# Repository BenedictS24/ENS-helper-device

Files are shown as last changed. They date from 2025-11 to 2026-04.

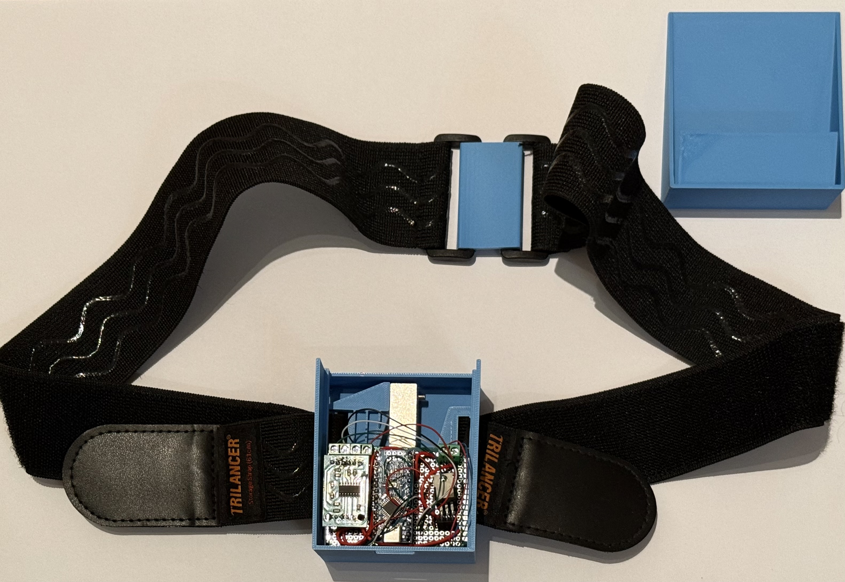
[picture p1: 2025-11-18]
images/device_open.jpeg

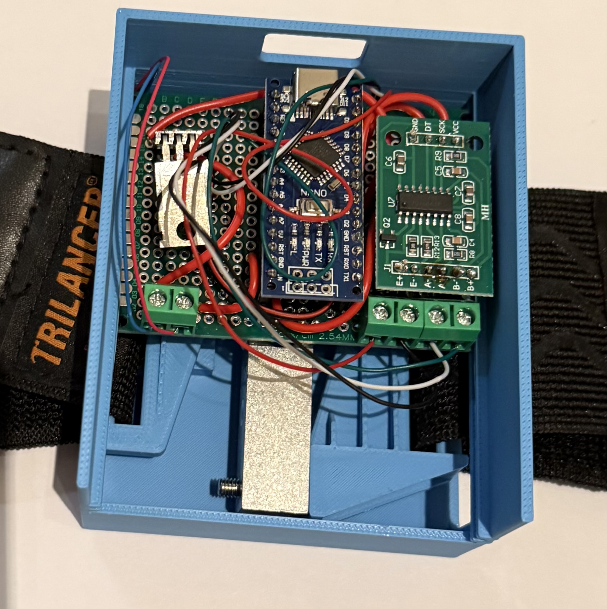
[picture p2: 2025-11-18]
images/protoboard_in_case.jpeg

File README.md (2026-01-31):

# ENS Helper Device

A chest-mounted haptic feedback belt that helps people with Empty Nose Syndrome (ENS) perceive their breathing again.
The device measures chest expansion using a load cell connected to a strap and translates this signal into vibrations via a small vibration motor embedded in the device.

---
## Repository Structure

```
ENS-helper-device/
├── .gitignore
├── KiCad/
│   ├── sensory_support_device.kicad_pcb
│   └── sensory_support_device.kicad_sch
├── README.md
├── force_vibration_controller/
│   └── force_vibration_controller.ino
├── images/
│   ├── PCB-3d.png
│   ├── PCB.png
│   ├── breadboard_circuit.jpeg
│   ├── circuit.png
│   ├── device_closed.jpeg
│   ├── device_open.jpeg
│   ├── device_worn.JPG
│   └── protoboard_in_case.jpeg
└── models/
    ├── back_plate.stl
    ├── load_cell_attachment.stl
    ├── main_plate.stl
    └── main_plate_cover.stl
```

---
## Overview

People with Empty Nose Syndrome often struggle to feel the airflow in their nose, which can make it harder to sense their own breathing and can greatly impact everyday life and well-being.  
This device offers an alternative channel: **haptic feedback on the chest**.

1. A chest strap attached to a **bar-type load cell** is placed around the chest.  
2. When the user inhales and exhales, the changing chest circumference alters the **force on the strap**.  
3. The load cell signal is amplified and read by an **Arduino Nano**.  
4. The firmware processes the signal and drives a **vibration motor** via a MOSFET transistor.  
5. The vibration pattern mirrors the breathing signal, giving the user a **tactile sense of their breathing**.

The firmware supports different modes, such as:

- **Absolute force** – vibration strength based on the total measured force  
- **Rate of change** – feedback based on how quickly the force changes during breathing

---

## Hardware

The prototype uses the following components:

- **Microcontroller:** Arduino Nano
- **Force sensor:** Bar-type load cell (approx. 20 kg)  
- **Amplifier:** HX711 load cell amplifier module  
- **Actuator:** Small cylindrical vibration motor  
- **Driver:** MOSFET
- **Mechanical parts:**  
  - Elastic chest strap  
  - 3D-printed enclosure and attachments (`models/`)  
  - M4/M5 Screws, nuts, protoboard  

---

## 3D-Printed Enclosure

The enclosure consists of the following STL files:

- `main_plate.stl` – holds load cell + electronics  
- `back_plate.stl` – attaches to the straps at the back  
- `load_cell_attachment.stl` – mount that connects the strap to the load cell
- `main_plate_cover.stl` – cover of main the enclosure 

Recommended print settings:

- Material: PLA or PETG
- Layer height: 0.16 mm
- Infill: 20–30 %
- Supports: minimal or only where necessary
  * You may need to adjust the print orientation 

---

## Firmware

The firmware (`force_vibration_controller.ino`) is responsible for:

- Reading load cell values via **HX711**  
- Detecting absolute force or force change  
- Driving the vibration motor using PWM  

Firmware parameters such as mode selection, calibration factors, and thresholds can be adjusted directly in the `.ino` file.

Upload using the Arduino IDE.

---

## Disclaimer

This project is a hobby / research prototype.  
It is **not** a medical device and must **not** be used as a substitute for professional medical treatment or diagnosis.  
Use at your own risk.

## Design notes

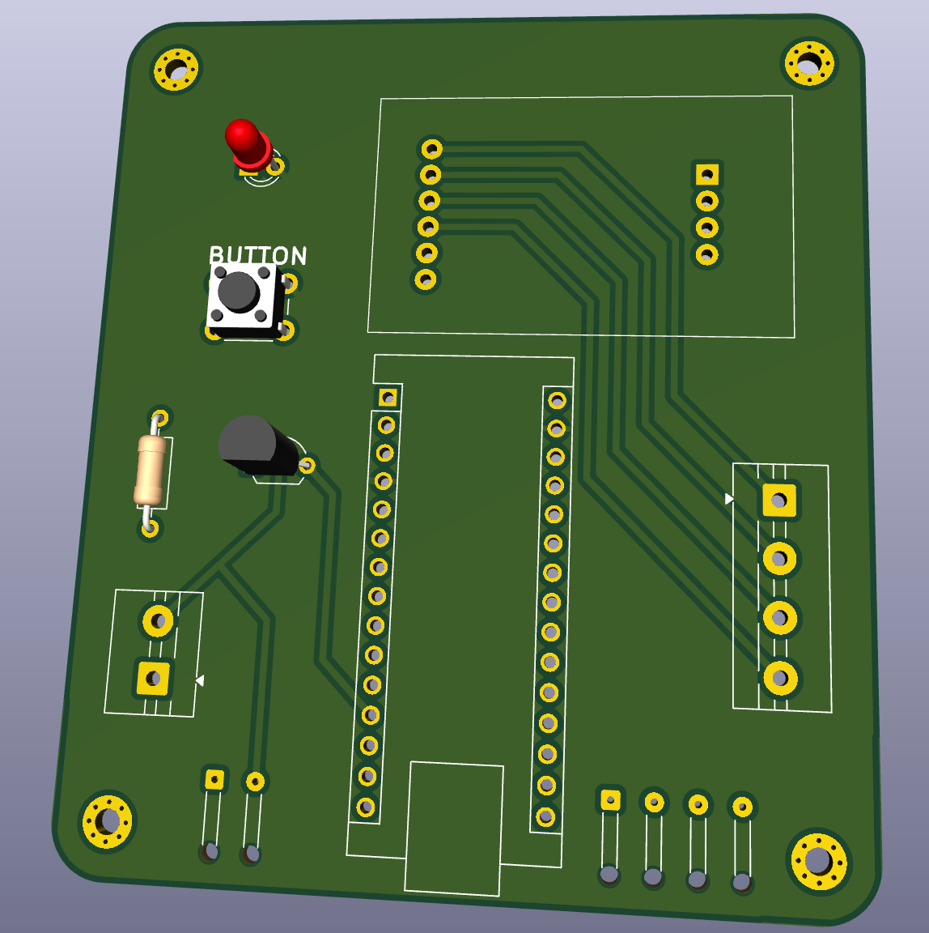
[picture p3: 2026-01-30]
images/PCB-3d.png

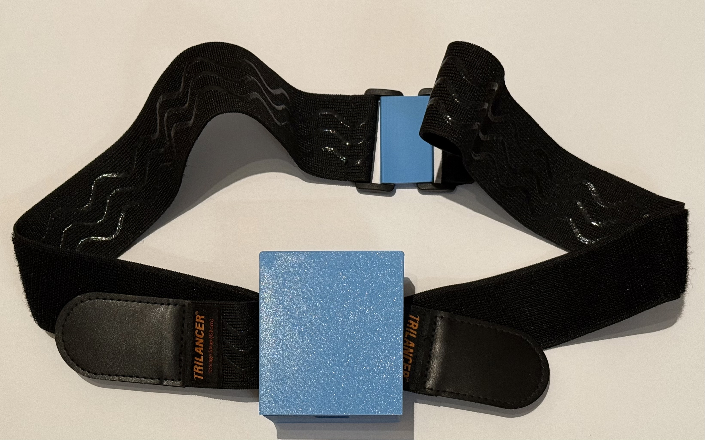
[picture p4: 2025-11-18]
images/device_closed.jpeg

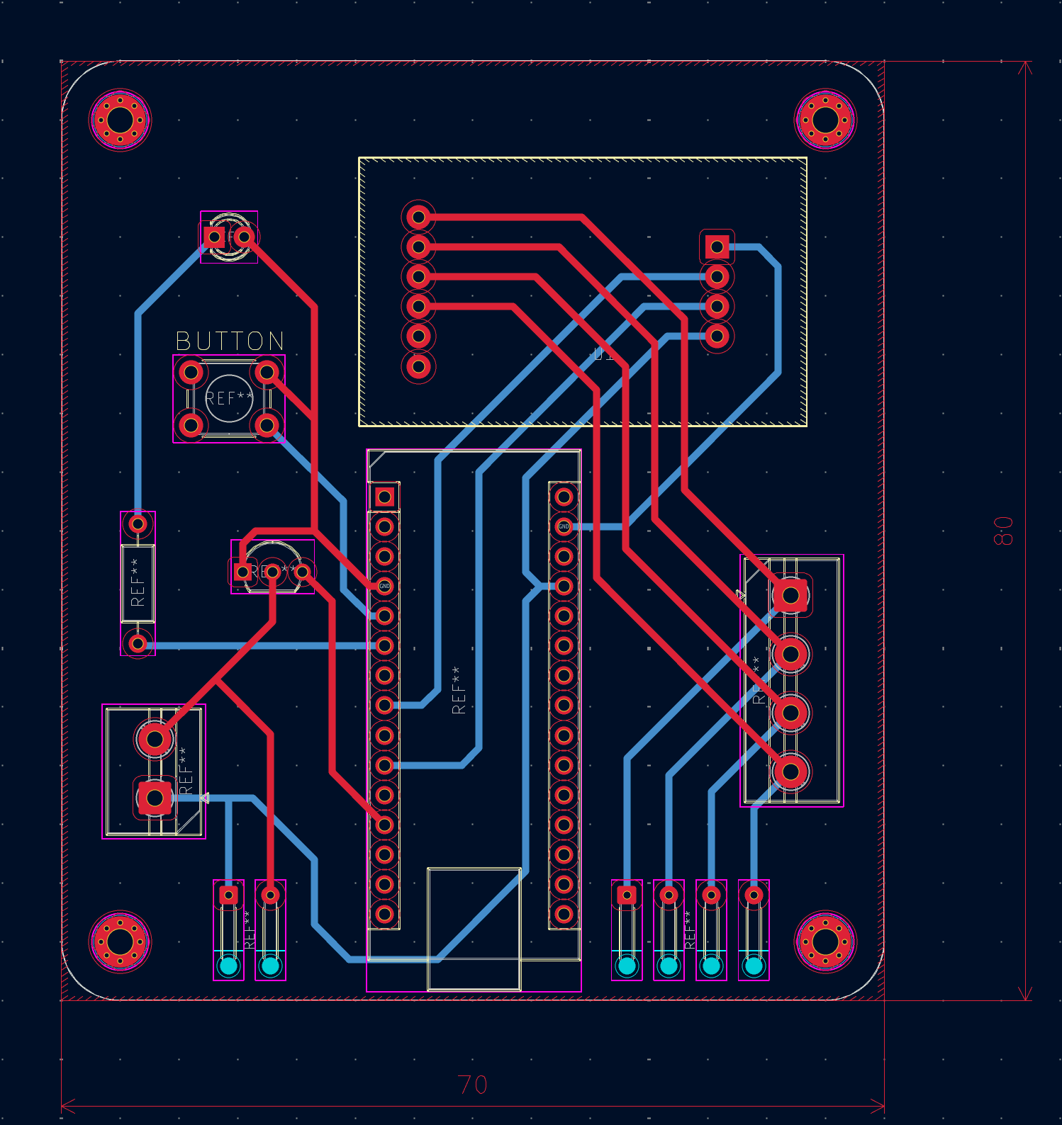
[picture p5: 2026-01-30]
images/PCB.png

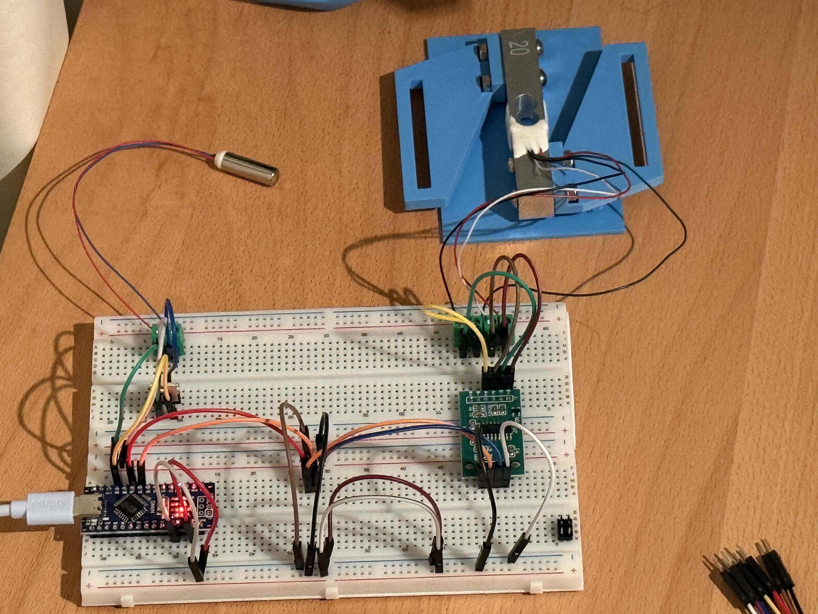
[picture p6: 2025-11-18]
images/breadboard_circuit.jpeg

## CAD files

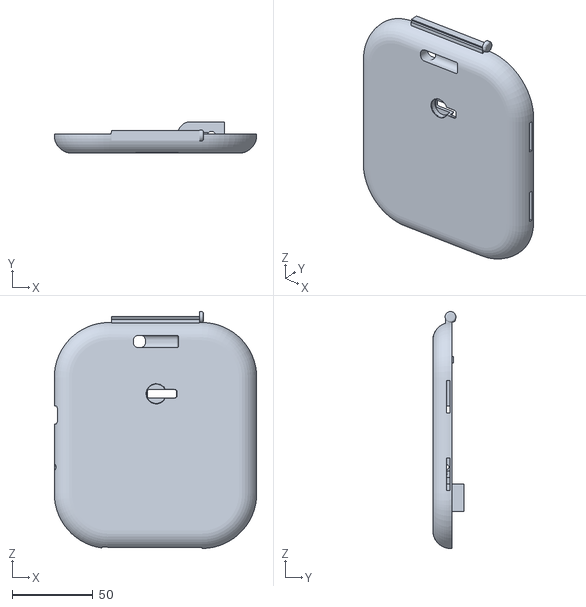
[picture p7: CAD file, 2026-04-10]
models/Housing-main_body.stl
125.4 x 19.5 x 146.8

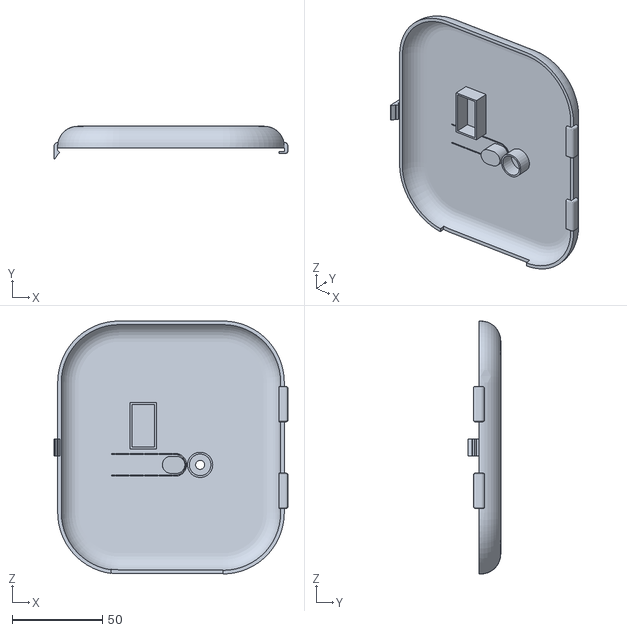
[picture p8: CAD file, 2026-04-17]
models/Housing-cover plate.stl
129.4 x 18.0 x 140.0

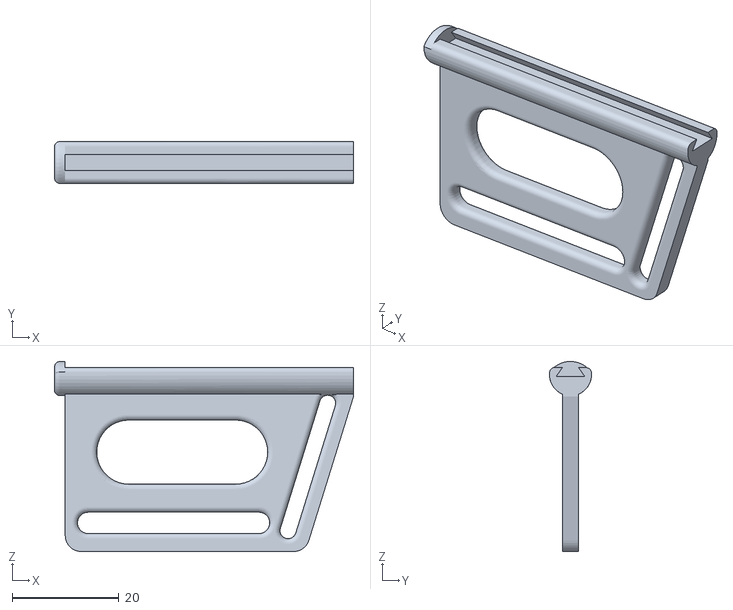
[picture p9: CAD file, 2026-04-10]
models/Housing-strap attachment.stl
56.0 x 7.88 x 35.6

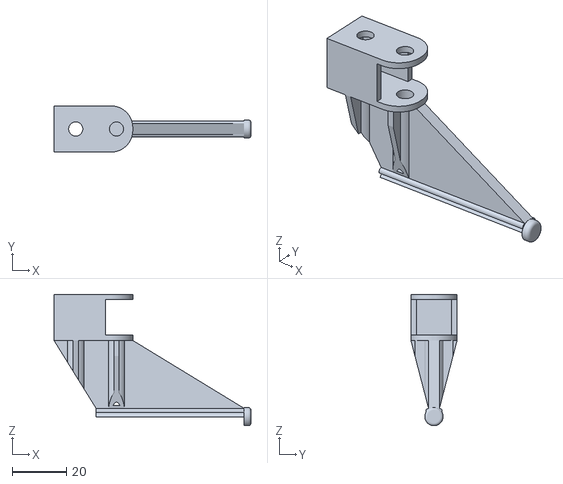
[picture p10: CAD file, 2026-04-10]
models/Housing-loadcell_arm.stl
72.5 x 17.0 x 48.4

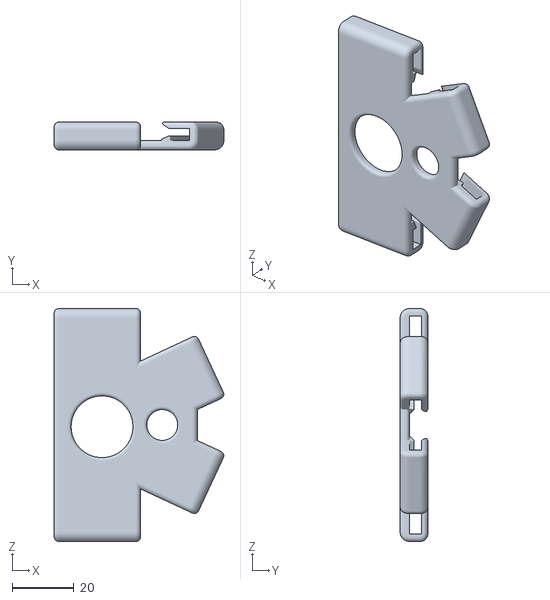
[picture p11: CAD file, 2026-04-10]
models/Housing-Backplate.stl
54.9 x 9.00 x 75.4

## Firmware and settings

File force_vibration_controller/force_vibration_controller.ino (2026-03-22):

#include "HX711.h"
#include <math.h>

// -------------------------------------------------------------
// Configuration
// -------------------------------------------------------------

// Set mode to either:
//   "absolute"      → vibration based on total force
//   "rate"          → vibration based on rate-of-change
String mode = "absolute";   // "absolute" or "rate"

// HX711 pins
const int PIN_DOUT = 7;
const int PIN_SCK = 9;

// Vibration motor
const int MOTOR_PIN = 5;

// Calibration values
long zero_offset = 102000;   // raw reading at no load
float scale_factor = 1000.0;   // raw units per gram

HX711 scale;

// ----- Absolute-force mode settings --------------------------------
float min_weight = 0.0;        // grams → no vibration below this
float max_weight = 2000.0;     // grams → max vibration at/above this

// ----- Rate-of-change mode settings -------------------------------
float last_weight = 0.0;       // grams
unsigned long last_time = 0;   // ms

float max_rate = 200.0;        // g/s mapped to max vibration
float min_rate = 0.0;          // vibration starts above this threshold

float rate_filtered = 0.0;
float smoothing = 0.1;        // exponential smoothing factor


// -------------------------------------------------------------
// Setup
// -------------------------------------------------------------
void setup() {
  Serial.begin(57600);

  scale.begin(PIN_DOUT, PIN_SCK);
  pinMode(MOTOR_PIN, OUTPUT);
  analogWrite(MOTOR_PIN, 0);

  // Initialize rate-of-change reference
  last_time = millis();
  long raw = scale.read();
  last_weight = (raw - zero_offset) / scale_factor;
}


// -------------------------------------------------------------
// Helper: read current weight in grams
// -------------------------------------------------------------
float get_weight() {
  long raw = scale.read();
  return (raw - zero_offset) / scale_factor;
}


// -------------------------------------------------------------
// Main loop
// -------------------------------------------------------------
void loop() {
  if (!scale.is_ready()) {
    Serial.println("HX711 not ready.");
    analogWrite(MOTOR_PIN, 0);
    delay(100);
    return;
  }

  float weight = get_weight();
  int pwm = 0;   // motor output (0–255)

  // -------------------------------------------------------------
  // Mode: ABSOLUTE FORCE
  // -------------------------------------------------------------
  if (mode == "absolute") {

    Serial.println(weight);

    float w = constrain(weight, min_weight, max_weight);
    pwm = map(w, min_weight, max_weight, 0, 255);
    analogWrite(MOTOR_PIN, pwm);
  }

  // -------------------------------------------------------------
  // Mode: RATE OF CHANGE
  // -------------------------------------------------------------
  else if (mode == "rate") {

    unsigned long now = millis();
    float dt = (now - last_time) / 1000.0;
    if (dt <= 0) dt = 0.001;

    float rate = (weight - last_weight) / dt;

    // Stabilize signal
    rate_filtered = smoothing * rate + (1.0 - smoothing) * rate_filtered;

    float r = fabs(rate_filtered);
    r = constrain(r, min_rate, max_rate);

    pwm = map(r, min_rate, max_rate, 0, 255);
    analogWrite(MOTOR_PIN, pwm);

    // For serial plotter: weight, rate, pwm
    Serial.print(weight, 2);
    Serial.print('\t');
    Serial.print(rate_filtered, 2);
    Serial.print('\t');
    Serial.println(pwm);

    last_weight = weight;
    last_time = now;
  }

  // -------------------------------------------------------------
  // Unknown mode
  // -------------------------------------------------------------
  else {
    Serial.println("Unknown mode, motor off.");
    analogWrite(MOTOR_PIN, 0);
  }

  delay(100);
}

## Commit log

2025-11-18 Added stl files and merged code files
    [Unnamed1 copy-Body.stl, Unnamed1 copy.FCStd, back plate.FCStd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]
2025-11-19 Add README for ENS Helper Device project
    Added detailed documentation for the ENS Helper Device, including repository structure, overview, hardware components, 3D-printed enclosure specifications, and firmware information.
2026-01-31 Uploading KiCad schematic
    [sensory_support_device.kicad_sch]
2026-01-31 Uploading KiCad pcb file
    [sensory_support_device.kicad_pcb]
2026-03-14 Refactor code structure for improved readability and maintainability
    [sensory_support_device.kicad_pcb]
2026-03-14 Enhance force vibration controller with no breath alert mode and improved signal processing
    [force_vibration_controller_with_button.ino]
2026-03-20 Enhance motor control by enforcing minimum PWM and adjusting debounce timing
2026-03-21 Refactor force vibration controller for improved calibration handling and normalized weight processing
    [force_vibration_controller_with_button.ino]
2026-03-21 Add motor signal for calibration mode with short pulses
    [force_vibration_controller_with_button.ino]
2026-03-22 Refactor variable names for consistency and readability in force vibration controller
    [force_vibration_controller.ino, force_vibration_controller_with_button.ino]
2026-03-28 Adjust minimum motor PWM to improve motor performance during operation
2026-03-30 Added additional feedback at the end of calibration
2026-03-31 Motor only runs after calibration
2026-03-31 Fix of calibration time
    [force_vibration_controller_with_button.ino]
2026-03-31 added max pwm to relative mode
2026-04-06 Added plotting for calibrated min und max
2026-04-10 Deleted old models and uploaded new main body
    [Housing-main_body.stl, back_plate.stl, load_cell_attachment.stl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]
2026-04-10 Uploaded new cover plate for the main housing
    [Housing-cover plate.stl]
2026-04-10 Uploaded new backpalte for the straps
    [Housing-Backplate.stl]
2026-04-10 Uploaded new strap and load cell attachments
    [Housing-loadcell_arm.stl, Housing-strap attachment.stl]
2026-04-10 Uploaded the assembled housing
2026-04-17 Added new cover plate
    [Housing-cover plate.stl]
2026-04-17 Added the Freecad file for the housing
2026-04-17 Updated cover plate
    [Housing-cover plate.stl]
2026-04-21 Changed motor and changed pwm values accordingly
2026-04-21 Added auto-tare functionality and adjusted calibration parameters
2026-04-22 Adjust display values by adding calibration offset for improved readability
2026-04-24 Increase minimum motor PWM and calibration signal PWM for improved performance; reduce no breath timeout for quicker response.
2026-04-24 Refactor button handling logic to improve long press detection and increase maximum alert PWM value for enhanced performance
2026-04-25 Added smoothing for calibration values
